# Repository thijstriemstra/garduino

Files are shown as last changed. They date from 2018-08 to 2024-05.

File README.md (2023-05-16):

Garduino
========

Greenhouse monitoring using ESP32.

## Features

- Controls 24V water waterpump and starts it once a day to water the plants for
  a period of time
- Device status is displayed on a small 0.91 inch OLED screen
- Includes a manual mode button to enable/disable the water valve manually
- Time is stored in a battery-powered DS3231 realtime clock

### Sensors

| Target | Sensor | Location | Amount |
| --- | --- | --- | --- |
| Light | TSL2591 | Inside | 1 |
| Soil moisture | Capacitive Soil Moisture Sensor v2.0 | Inside | 8 |
| Temperature/pressure/humidity | BME280 | Inside | 1 |
| Air temperature | DS18B20 | Outside | 1 |
| Water temperature | DS18B20 | Outside | 1 |

Readings from the sensors are sent to a MQTT server over WiFi (if available).

## Wiring

### AZ-Delivery Devkit V4

| Device | Pin Label | ESP32 Pin | Type |
| --- | --- | --- | --- |
| TCA9548A I2C Expander | SDA | `4` | I2C bus 0 (address: `0x70`) |
| TCA9548A I2C Expander | SCL | `22` | I2C bus 0 (address: `0x70`) |
| DS3231 Realtime Clock | SDA | `4` | I2C bus 0 (address: `0x68`) |
| DS3231 Realtime Clock | SCL | `22` | I2C bus 0 (address: `0x68`) |
| AT24C32 EEPROM on DS3231 | SDA | `4` |  I2C bus 0 (address: `0x57`) |
| AT24C32 EEPROM on DS3231 | SCL | `22` |  I2C bus 0 (address: `0x57`) |
| PCF8574 Digital Expander | SDA | `4` |  I2C bus 0 (address: `0x20`) |
| PCF8574 Digital Expander | SCL | `22` |  I2C bus 0 (address: `0x20`) |
| MCP3008 Analog Expander | CLK | `18` | SCK |
| MCP3008 Analog Expander | DOUT | `19` | MISO |
| MCP3008 Analog Expander | DIN | `23` | MOSI |
| MCP3008 Analog Expander | CS | `5` | SS |
| DS18B20 Temperature Sensors | GPIO | `13` | Digital Input |
| Buzzer | GPIO | `25` | Digital Output |
| Single Channel Relay | GPIO | `26` | Digital Output |
| Manual Run Button | GPIO | `39` | Digital Input |
| Power Button | GPIO | `36` | Digital Input |

### TCA9548A

| Device | Pin Label | TCA9548A Pin | Address |
| --- | --- | --- | --- |
| TSL2591 light sensor | SDA | `SD0` | `0x29` |
| TSL2591 light sensor | SCL | `SC0` | `0x29` |
| BME280 barometer | SDA | `SD1` | `0x76` |
| BME280 barometer | SCL | `SC1` | `0x76` |
| 0.91" OLED Display | SDA | `SD2` | `0x3C` |
| 0.91" OLED Display | SCL | `SC2` | `0x3C` |

### PCF8574

| Device | Type | PCF8574 Pin |
| --- | --- | --- |
| Watering Indication LED (White) | Digital Output | `0` |
| Manual Run LED (Yellow) | Digital Output | `2` |
| Network LED (Blue) | Digital Output | `1` |
| Power LED (Red) | Digital Output | `3` |

### MCP3008

| Device | Type | MCP3008 Pin |
| --- | --- | --- |
| Capacitive Soil 1 | Analog Input | `0` |
| Capacitive Soil 2 | Analog Input | `1` |
| Capacitive Soil 3 | Analog Input | `2` |
| Capacitive Soil 4 | Analog Input | `3` |
| Capacitive Soil 5 | Analog Input | `4` |
| Capacitive Soil 6 | Analog Input | `5` |
| Capacitive Soil 7 | Analog Input | `6` |
| Capacitive Soil 8 | Analog Input | `7` |

## 3D Printable Parts

| Part | Amount |
| --- | --- |
| [Buck converter bottom](cad/buck-converter-bottom.stl) | 1 |
| [Buck converter top](cad/buck-converter-top.stl) | 1 |
| [Buck converter icon](cad/buck-converter-icon.stl) | 1 |
| [Buck converter latch](cad/buck-converter-latch.stl) | 2 |

## Output

Example of cycle report on serial line:

```
00:00:00.063  ========================
00:00:00.064  =    garduino v4.0.0   =
00:00:00.064  ========================
00:00:00.065  Board:       AZ-Delivery ESP-32 Dev Kit C V4
00:00:00.075  Arduino:     2.0.7
00:00:00.075  ESP-IDF:     v4.4.4
00:00:00.080  Local time:  17:46:17
00:00:00.485  *******************************************
00:00:00.486  Wakeup reason: timer (60 sec)
00:00:00.487  *******************************************
00:00:00.488  WiFi - SSID: my_ssid
00:00:00.499  WiFi - Connecting...
00:00:00.708  WiFi - Connected.
00:00:00.709  WiFi - Hostname: garduino
00:00:00.709  Wifi - IP address: 192.168.2.2
00:00:00.710  ================================
00:00:00.721  MQTT - Timeout set to 30 seconds
00:00:00.721  MQTT - Broker: 192.168.2.1:1883
00:00:00.722  MQTT - Connecting...
00:00:00.775  MQTT - Connected.
00:00:00.776  ================================
00:00:00.777
00:00:00.777  ************************************
00:00:00.778        Watering: No
00:00:00.788          Period: 60 sec
00:00:00.789  Daily schedule: 19:00:00
00:00:00.789    Current time: 17:46:17
00:00:00.791        Last run: 2023-03-21 19:08:11
00:00:00.802  ************************************
00:00:00.802
00:00:00.803  MQTT - Publishing sensor data...
00:00:00.813
00:00:00.814  Inside
00:00:00.814  ------
00:00:00.814
00:00:00.815  Light:            350.67 lx
00:00:00.821  Humidity:         44.5%
00:00:00.822  Temperature:      25.14 °C
00:00:00.822  Pressure:         1002.44 hPa
00:00:00.840  Soil-1 wet:       0%
00:00:00.841  Soil-2 wet:       0%
00:00:00.851  Soil-3 wet:       0%
00:00:00.852  Soil-4 wet:       0%
00:00:00.852  Soil-5 wet:       0%
00:00:00.852  Soil-6 wet:       0%
00:00:00.853  Soil-7 wet:       98%
00:00:00.863  Soil-8 wet:       0%
00:00:00.854  System:           23.75 °C
00:00:00.854
00:00:00.854  Outside
00:00:00.855  -------
00:00:00.865
00:00:00.962  Temperature:      17.75 °C
00:00:00.967
00:00:00.967  Water
00:00:00.967  -----
00:00:00.967
00:00:00.968  Temperature:      18.25 °C
00:00:00.968
00:00:00.968  WIFI
00:00:00.969  ----
00:00:00.979
00:00:00.981  RSSI:             -63 dBm
00:00:00.981
00:00:00.981  **********************************************
00:00:00.982
00:00:16.558  MQTT - Published 16 messages.
00:00:16.559  MQTT - Disconnecting...
00:00:16.863
00:00:16.864  ******************************
00:00:16.865  **  Going to sleep... Bye.  **
00:00:16.866  ******************************
```

## Local NTP Server

Setup a local NTP server instead of fetching this information online every
time.

```console
sudo apt-get install ntp
```

Verify installation:

```console
sntp --version
```

Switch the server pool to the ones closest to your location. Go to
https://support.ntp.org/bin/view/Servers/NTPPoolServers and find the
nearest pool, e.g. Europe. Update `/etc/ntp.conf` accordingly:

```
	   server 0.europe.pool.ntp.org
	   server 1.europe.pool.ntp.org
	   server 2.europe.pool.ntp.org
	   server 3.europe.pool.ntp.org
```

Restart the server:

```console
sudo service ntp restart
```

Check the status:

```console
 sudo service ntp status
 ```

You can now use this machine for NTP time synchronization on the ESP32.

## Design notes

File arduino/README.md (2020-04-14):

Arduino code for garden monitoring using ESP32.

This project was created using a Lolin32 Lite v1.0.0.

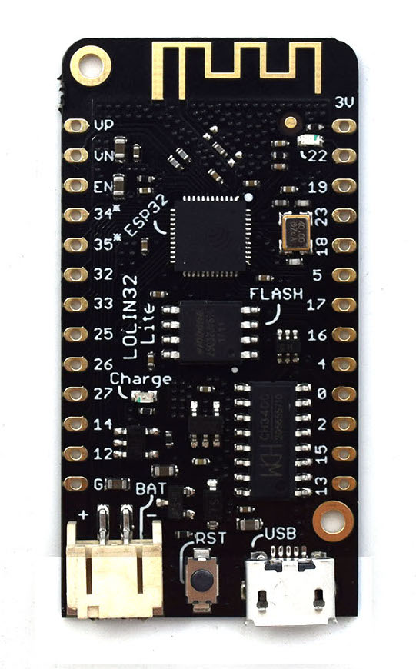
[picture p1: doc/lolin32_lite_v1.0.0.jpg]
Lolin32 Lite


## Installation

Checkout code:

```console
git clone https://github.com/thijstriemstra/py-garden.git
cd py-garden/arduino
```

## Development

Open `pygarden` project in VSCode with PlatformIO IDE extension.

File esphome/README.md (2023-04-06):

# ESPHome

Checkout the code:

```console
git clone https://github.com/thijstriemstra/garduino.git
cd garduino
```

Create a [virtual environment](https://virtualenvwrapper.readthedocs.io/en/latest/index.html)
called `garduino`:

```console
mkvirtualenv garduino
```

Install the dependencies:

```console
pip install -e .
```

Verify installation:

```console
esphome version
```

Create `secrets.yaml`:

```console
touch secrets.yaml
```

And make sure to add all options marked with `!secret` in `garduino.yaml`.

### Upload

Plug in the device via USB and type the following command:

```console
esphome run garduino.yaml
```

You should see ESPHome validating the configuration and telling you about
potential problems. Then ESPHome will proceed to compile and upload the
custom firmware.

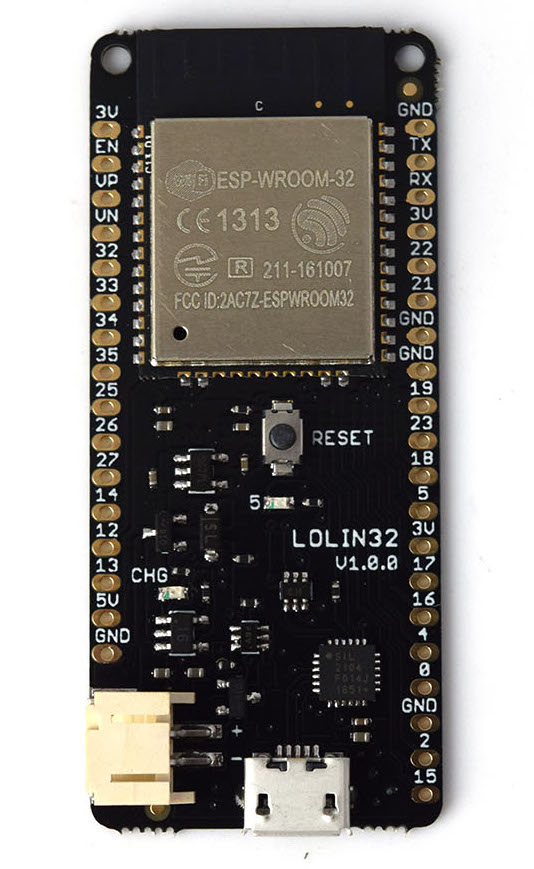
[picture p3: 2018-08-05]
micropython/doc/lolin32_v1.0.0.jpg

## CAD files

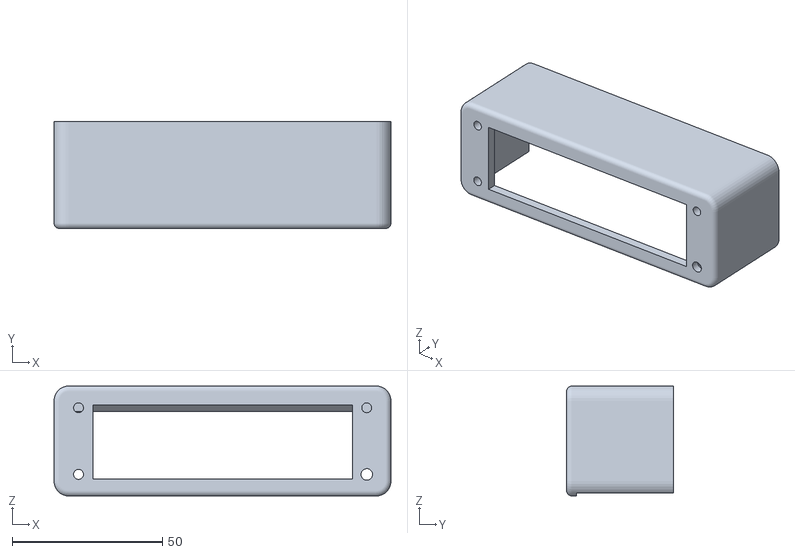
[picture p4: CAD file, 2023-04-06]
cad/Bottom Cover.stl
112.0 x 35.5 x 36.6

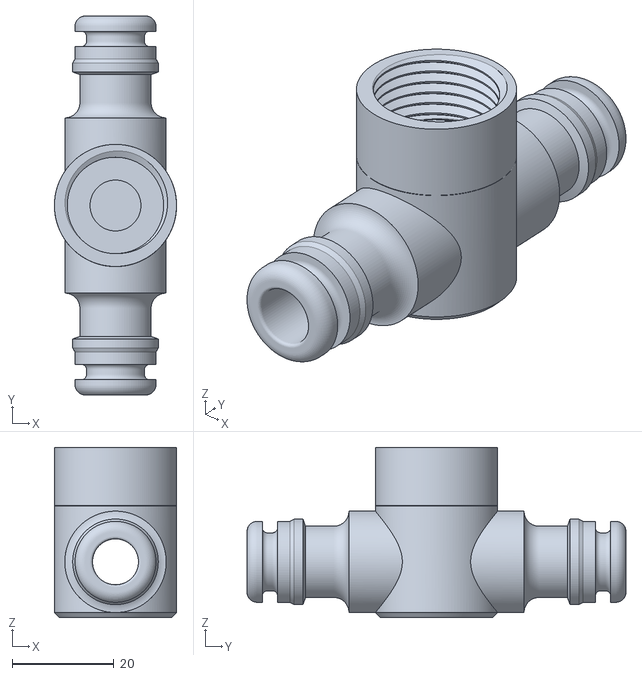
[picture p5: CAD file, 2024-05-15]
cad/irrigation/middle_section_2gardena_v1_0.5NTP.stl
24.0 x 74.4 x 33.4

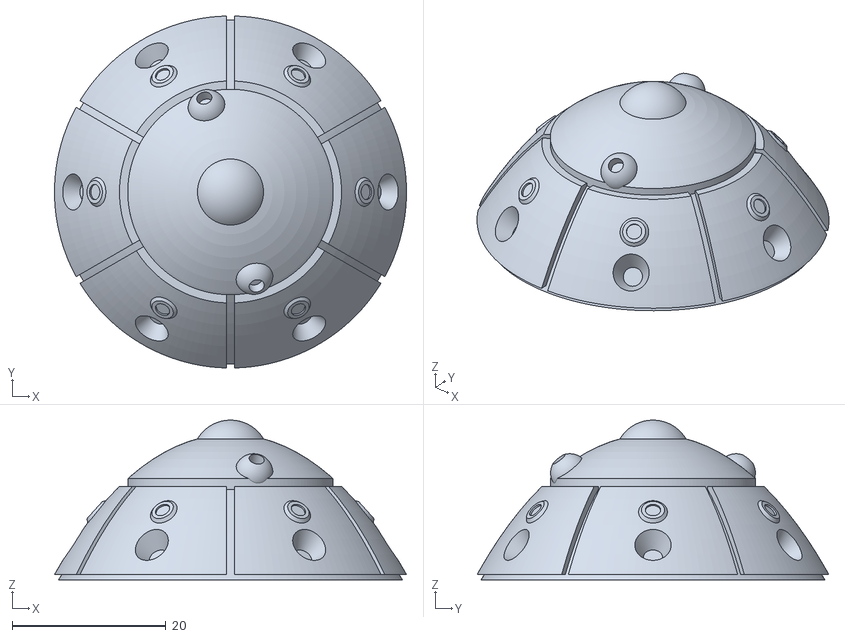
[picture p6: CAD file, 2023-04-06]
cad/sensors/top.stl
45.8 x 45.8 x 20.8

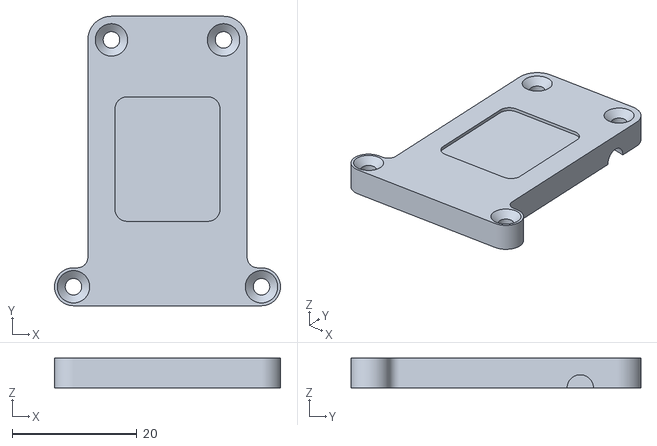
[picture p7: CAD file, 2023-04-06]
cad/soil/soil-sensor-lid.stl
36.3 x 46.5 x 4.80

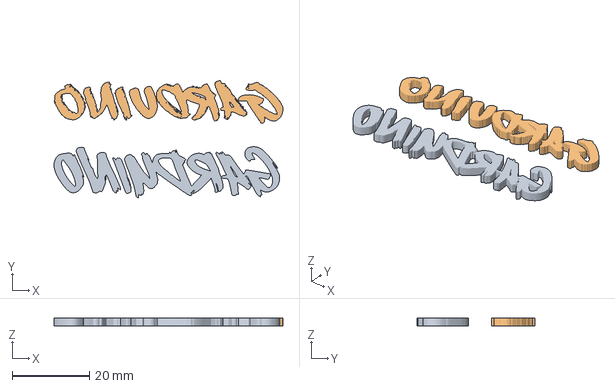
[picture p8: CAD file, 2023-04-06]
cad/Garduino-logo .3mf
59.3 x 30.5 x 2.00 mm
Garduino
Garduino

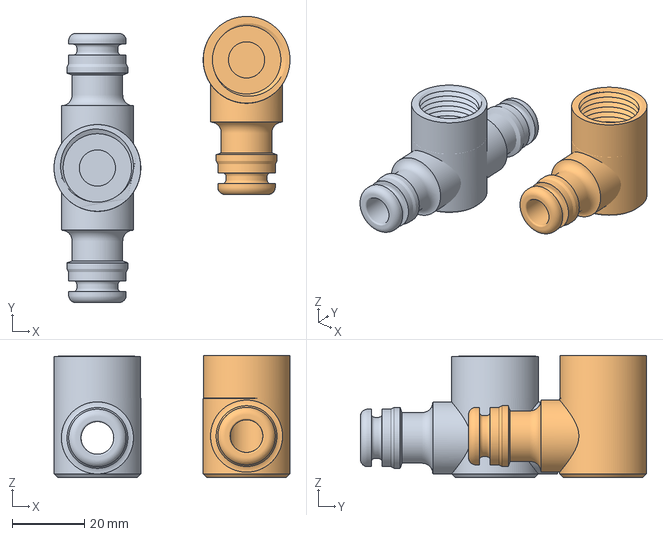
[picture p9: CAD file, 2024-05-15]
cad/irrigation/middle_section_0.5NTP.3mf
65.2 x 79.1 x 33.7 mm
middle_section_2gardena_v1_0.5NTP.stl
middle_section_1gardena_v1_0.5NTP.stl

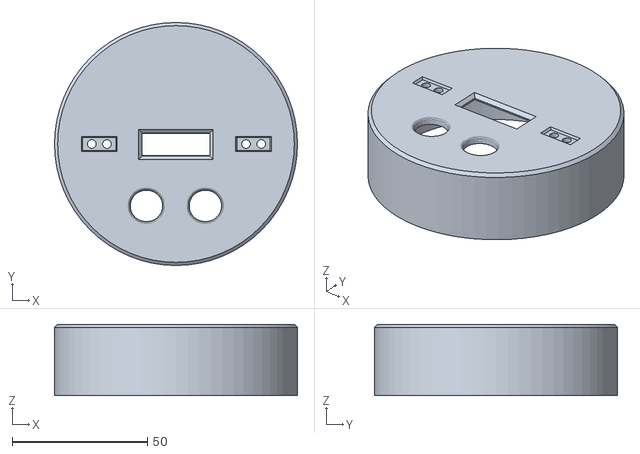
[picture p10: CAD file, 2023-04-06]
cad/sensors/ctrl-panel-cap.stl
90.0 x 90.0 x 26.4

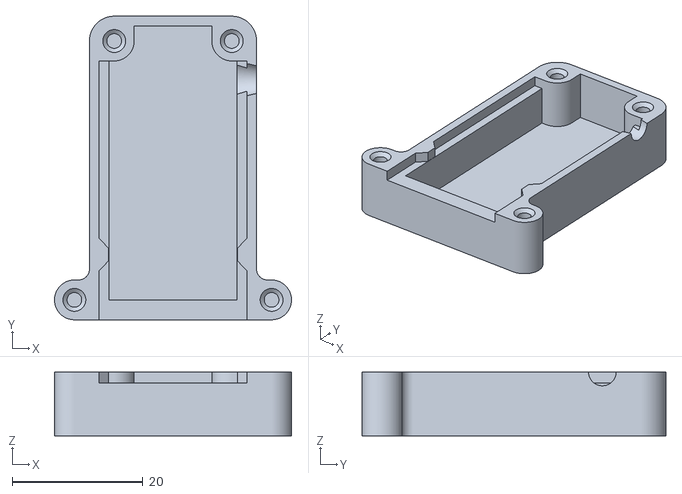
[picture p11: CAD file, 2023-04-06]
cad/soil/soil-sensor-box.stl
36.3 x 46.5 x 9.80

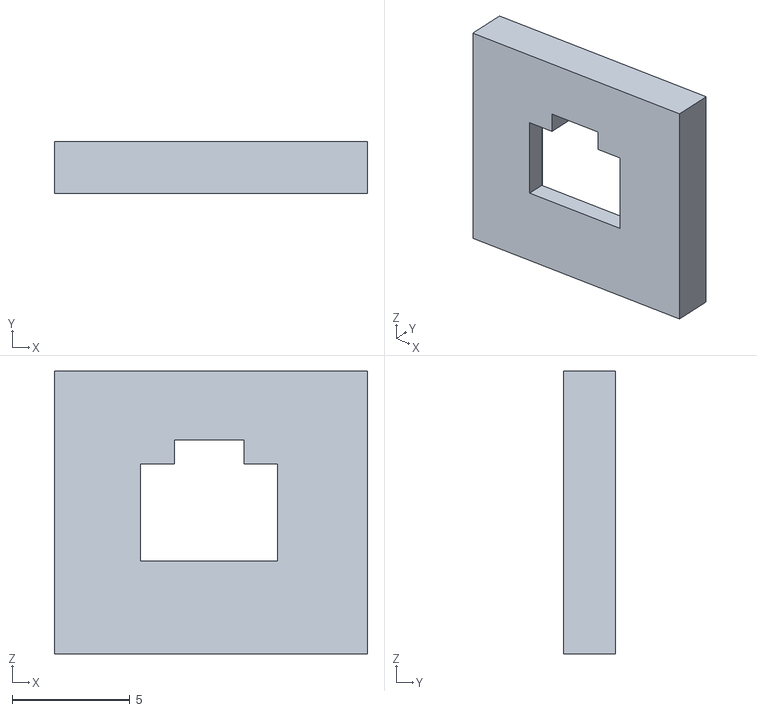
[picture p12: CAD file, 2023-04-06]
cad/conn-2-pin-cover.stl
13.3 x 2.20 x 12.0

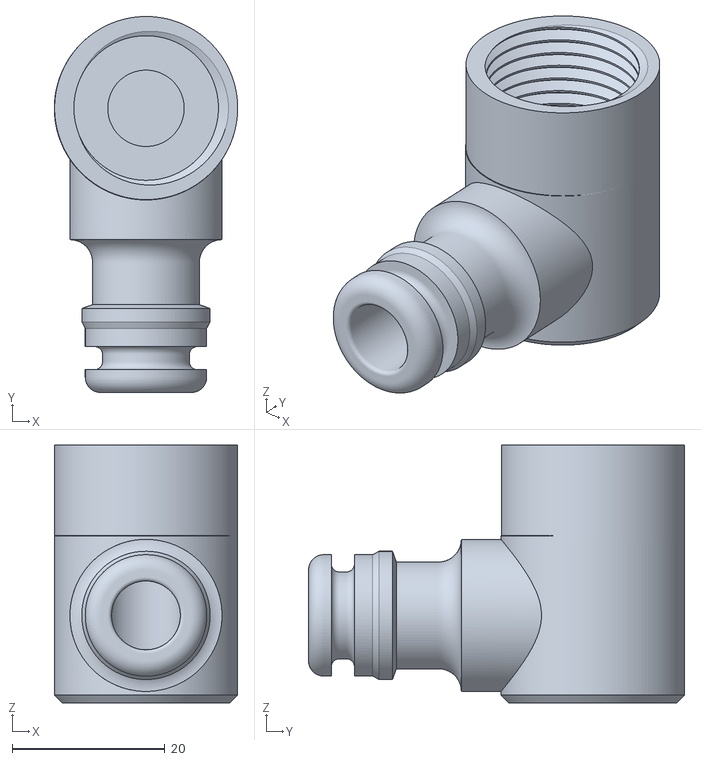
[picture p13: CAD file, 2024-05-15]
cad/irrigation/middle_section_1gardena_v1_0.5NTP.stl
24.0 x 49.2 x 33.7

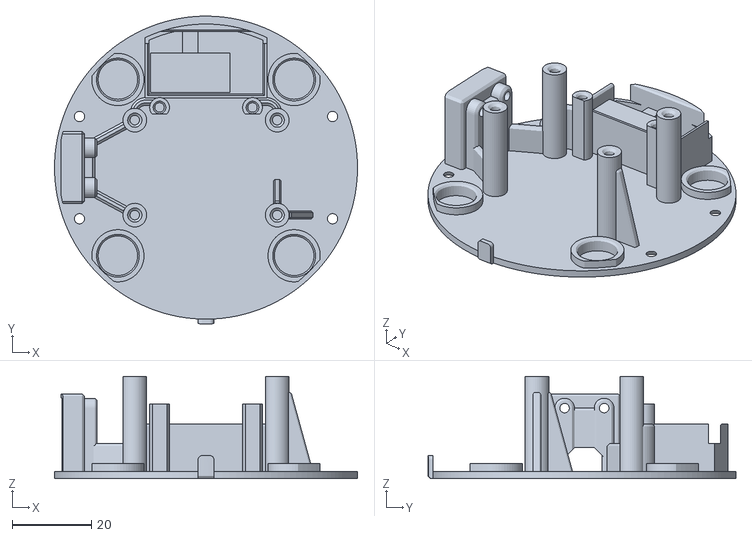
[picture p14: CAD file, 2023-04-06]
cad/sensors/ctrl-panel-bottom.stl
76.6 x 77.8 x 25.8

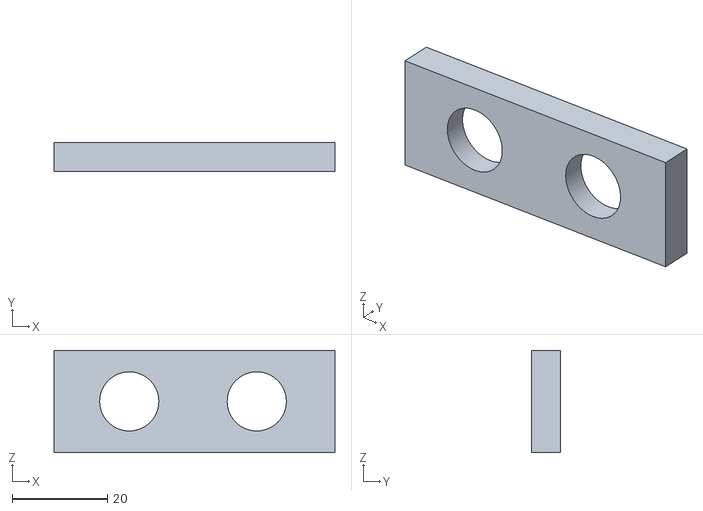
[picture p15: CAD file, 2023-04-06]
cad/case-connectors.stl
58.9 x 6.17 x 21.4

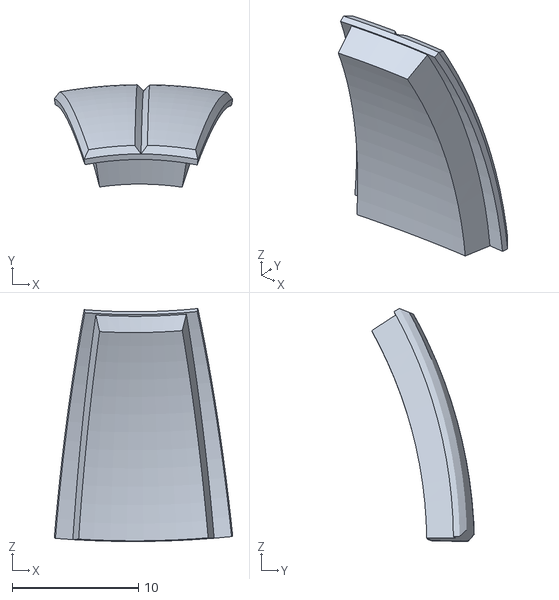
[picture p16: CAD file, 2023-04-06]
cad/sensors/door1.stl
14.2 x 8.13 x 18.5

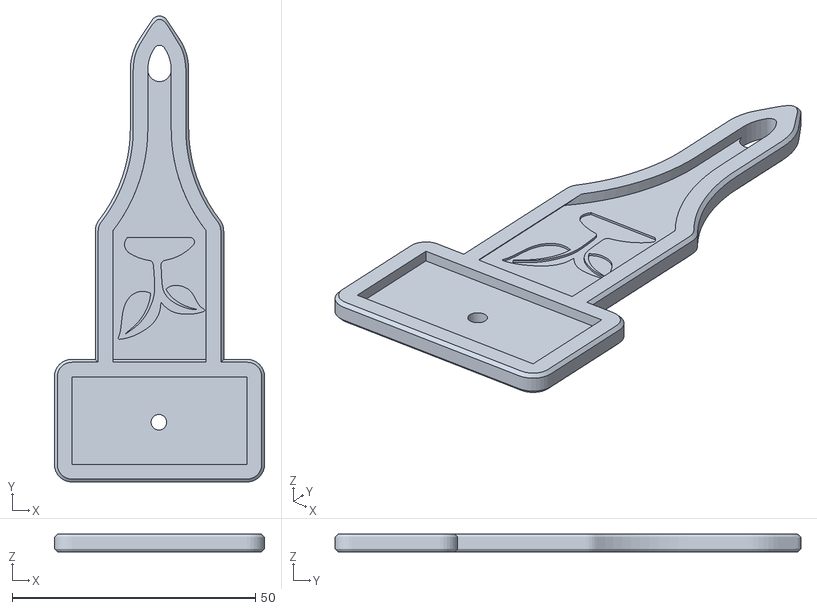
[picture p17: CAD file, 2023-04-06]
cad/plant-label.stl
43.2 x 95.8 x 3.60

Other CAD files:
cad/sensors/ring.stl
cad/plant-label-card.stl
cad/sensors/icon-moon.stl
cad/handle-right.stl
cad/Bottom Connectors.stl
cad/Bottom Shell PCB only.stl
cad/Top Shell.stl
cad/bme280-holder.stl
cad/bme280-top.stl
cad/buck-converter-bottom.stl
cad/buck-converter-icon.stl
cad/buck-converter-latch.stl
cad/buck-converter-top.stl
cad/buck-converter.blend
cad/case-bottom.stl
cad/case-top.stl
cad/conn-6-pin-cover.stl
cad/mcp3008.blend
cad/plant-label.blend
cad/sensors/case-bottom.stl
cad/sensors/case-top.stl
cad/sensors/ctrl-panel-button-cap.stl
cad/sensors/ctrl-panel-description.stl
cad/sensors/ctrl-panel-front.stl
cad/sensors/ctrl-panel-top.stl
cad/sensors/door2.stl
cad/sensors/icon-play.stl
cad/sensors/icon-power.stl
cad/sensors/thrusters.stl
cad/soil/soil-sensor.blend
cad/tsl2591-light-sensor.stl

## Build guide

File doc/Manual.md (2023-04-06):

# Garduino Manual

De Garduino geeft dagelijks om 19:00 uur de planten enige tijd water.

## Handmatige bediening

Je kan met de MANUAL knop de planten handmatig water geven.

In manual mode word er ook iedere 4 seconden op het display afwisselend
verschillende data weergegeven, zoals de huidige temperatuur en tijd.

### Stappen voor handmatig watergeven

1. Druk op de MANUAL knop tot de temperatuur op het display te zien is.
   Als het oranje licht op de voorzijde brandt, ga naar stap 2.

2. Druk nogmaals op de MANUAL knop om de waterpomp te starten.
   Het witte licht op de voorzijde brandt nu en op het display
   is 'Open' te zien.

3. Druk nogmaals op de MANUAL knop om de waterpomp te stoppen.
   Het witte licht op voorzijde zal uitgaan en op het display
   is weer 'Closed' te zien. Na 5 seconden zal de temperatuur
   en tijd weer afwisselend worden weergegeven.

4. Druk op de SLEEP knop om de Garduino weer het automatische
   programma te laten volgen. Op de voorzijde moeten nu alle lichten
   en het display uit zijn.

Vergeet niet stap 4 anders start de Garduino het automatische programma
niet op (en zal er dagelijks dus geen water worden gegeven).

---

v4.0.0

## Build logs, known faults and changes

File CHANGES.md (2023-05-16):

Garduino changelog
==================

4.1.0 (unreleased)
------------------

- Replace BH1750 with TSL2591 light sensor

4.0.0 (2023-04-08)
------------------

- Add buzzer
- Remove waterflow meter
- Fix soil sensors
- Add PC8574
- Unpin and use latest RTClib
- Add V4 CAD models

3.4.0 (2022-03-13)
------------------

- Pin RTClib @ 1.13.0

3.2.0 (2021-06-30)
------------------

- Display time and temperature on display
- Bug fixes

3.0.0 (2021-05-19)
------------------

Add support for:

- TCA9548A I2C expander
- MCP3008 analog expander

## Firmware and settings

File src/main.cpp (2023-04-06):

/*
* Copyright (c) 2020-2023 Collab
* All rights reserved
*/

#include "Garduino.h"

// *************************************************************************
//  Uncomment line below to fully disable logging, and reduce project size
// ************************************************************************
//#define DISABLE_LOGGING

#define SERIAL_BAUD_RATE 115200

Garduino *app = new Garduino();

void setup() {
  // start serial connection
  Serial.begin(SERIAL_BAUD_RATE);

  app->begin();
}

void loop() {
  app->loop();
}

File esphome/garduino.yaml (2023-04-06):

esphome:
  name: garduino

  project:
    name: "thijstriemstra.garduino"
    version: "4.0.0"

  platformio_options:
    upload_speed: 115200

#  on_boot:
#    then:
#      # read the RTC time once when the system boots
#      ds1307.read_time:

esp32:
  board: az-delivery-devkit-v4
  framework:
    type: arduino

# Enable logging
logger:

# Enable Home Assistant API
#api:
#  password: ""

ota:
  password: ""

wifi:
  ssid: !secret wifi_ssid
  password: !secret wifi_password
  # The amount of time to wait before rebooting when no WiFi connection exists.
  reboot_timeout: 15min

  # Enable fallback hotspot (captive portal) in case wifi connection fails
  ap:
    ssid: !secret hotspot_ssid
    password: !secret hotspot_password
    # The time after which to enable the configured fallback hotspot
    ap_timeout: 1min

captive_portal:

# ---------------------------
# Fonts
# ---------------------------
font:
  - file: "fonts/Arimo-Regular-Latin.ttf"
    id: arimo_regular_20
    size: 20
  - file: "fonts/Arimo-Regular-Latin.ttf"
    id: arimo_regular_30
    size: 30

# -----------------------------------
# Dallas temperature sensor (DS18B20)
# -----------------------------------

#dallas:
#  - pin: GPIO13

# -----------------------------------
# I2C
# -----------------------------------
#  - Bus 0: DS3231 RTC (0x68)
#  - Bus 0: AT24C32 EEPROM on DS3231 (0x57)
#  - Bus 1: TCA9548A I2C expander (0x70)
i2c:
  - id: bus_0
    frequency: 200kHz
    sda: GPIO16
    scl: GPIO17
    scan: true
  - id: bus_1
    frequency: 200kHz
    sda: GPIO4
    scl: GPIO22
    scan: true

# I2C expander:
#  - Channel 0: BH1750 light sensor (0x23)
#  - Channel 1: BME280 barometer (0x76)
#  - Channel 2: SSD1306 OLED (0x3C)
tca9548a:
  - id: multiplex0
    address: 0x70
    i2c_id: bus_1
    channels:
      - bus_id: multiplex0channel0
        channel: 0
      - bus_id: multiplex0channel1
        channel: 1
      - bus_id: multiplex0channel2
        channel: 2

# -----------------------------------
# SPI
# -----------------------------------
#  - MCP3008 analog expander
#spi:
#  clk_pin: GPIO18
#  mosi_pin: GPIO23
#  miso_pin: GPIO19

# Analog expander:
#  - Capacitive Soil Sensor x 5
#mcp3008:
#  id: soil_mcp
#  cs_pin: GPIO5

# ---------------------------
# Sensors
# ---------------------------

#sensor:
#  - platform: bh1750
#    name: "BH1750 Illuminance"
#    i2c_id: multiplex0channel0
#    address: 0x23
#    update_interval: 60s
#
#  - platform: bme280
#    temperature:
#      name: "BME280 Temperature"
#      oversampling: 16x
#    pressure:
#      name: "BME280 Pressure"
#    humidity:
#      name: "BME280 Humidity"
#    address: 0x76
#    update_interval: 60s
#    i2c_id: multiplex0channel1

#  - platform: dallas
#    address: 0xA40000031F055028
#    name: "Temperature #1"

#  - platform: mcp3008             # Attached to pin 0 of the MCP3008.
#    reference_voltage: 3.19
#    update_interval: 1s
#    mcp3008_id: soil_mcp
#    id: freezer_temp_source
#    number: 0                     # MCP3008 pin number
#  - platform: resistance
#    id: freezer_resistance_sensor
#    sensor: freezer_temp_source
#    configuration: DOWNSTREAM
#    resistor: 10kOhm
#  - platform: ntc
#    id: freezer_temp
#    sensor: freezer_resistance_sensor
#    calibration:
#      b_constant: 3950
#      reference_temperature: 25°C
#      reference_resistance: 10kOhm
#    name: Freezer Temperature

# ---------------------------
# Display
# ---------------------------

display:
  - platform: ssd1306_i2c
    model: "SSD1306 128x32"
    i2c_id: multiplex0channel2
    external_vcc: true
    address: 0x3C
    contrast: 100%
    rotation: 0°
    flip_x : true
    flip_y: true
    invert: false
    update_interval: 1s
    lambda: |-
      it.line(0, 0, 10, 20);

# ---------------------------
# Relay
# ---------------------------

#switch:
#  - platform: gpio
#    name: "Relay"
#    pin: GPIO2

# ---------------------------
# Buttons
# ---------------------------

#binary_sensor:
#  # Manual run button
#  - platform: gpio
#    pin: GPIO36
#    name: "Manual"
#    filters:
#      - delayed_on: 10ms
#
#  # Power button
#  - platform: gpio
#    pin: GPIO39
#    name: "Power"
#    filters:
#      - delayed_on: 10ms

# ---------------------------
# LED
# ---------------------------

#status_led:
#  pin:
#    number: GPIO33
#    inverted: false

output:
  # Watering indication LED
  - platform: gpio
    pin: GPIO25
    id: watering_led

  # Manual run LED
  - platform: gpio
    pin: GPIO26
    id: manual_led

  # Network LED
  - platform: gpio
    pin: GPIO33
    id: network_led

  # Power LED
  - platform: gpio
    pin: GPIO27
    id: power_led
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

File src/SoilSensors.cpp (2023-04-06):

/*  Copyright (c) 2020-2023, Collab
 *  All rights reserved
*/
/*
  SoilSensors.cpp - Read multiple Capacitive Soil Moisture Sensors.
*/
#include "SoilSensors.h"

SoilSensors::SoilSensors(SoilSensorsConfig cfg, MultiPlexer_MCP3008 *adc) {
  _soil1 = new Capacitive_SoilSensor_MCP3008(adc, cfg.sensor1_channel, cfg.sensor1_wet, cfg.sensor1_dry);
  _soil2 = new Capacitive_SoilSensor_MCP3008(adc, cfg.sensor2_channel, cfg.sensor2_wet, cfg.sensor2_dry);
  _soil3 = new Capacitive_SoilSensor_MCP3008(adc, cfg.sensor3_channel, cfg.sensor3_wet, cfg.sensor3_dry);
  _soil4 = new Capacitive_SoilSensor_MCP3008(adc, cfg.sensor4_channel, cfg.sensor4_wet, cfg.sensor4_dry);
  _soil5 = new Capacitive_SoilSensor_MCP3008(adc, cfg.sensor5_channel, cfg.sensor5_wet, cfg.sensor5_dry);
  _soil6 = new Capacitive_SoilSensor_MCP3008(adc, cfg.sensor6_channel, cfg.sensor6_wet, cfg.sensor6_dry);
  _soil7 = new Capacitive_SoilSensor_MCP3008(adc, cfg.sensor7_channel, cfg.sensor7_wet, cfg.sensor7_dry);
  _soil8 = new Capacitive_SoilSensor_MCP3008(adc, cfg.sensor8_channel, cfg.sensor8_wet, cfg.sensor8_dry);
}

void SoilSensors::begin() {
}

SoilMoistureResult SoilSensors::readAll() {
  SoilMoistureResult result;
  result.sensor1 = _soil1->measure();
  result.sensor2 = _soil2->measure();
  result.sensor3 = _soil3->measure();
  result.sensor4 = _soil4->measure();
  result.sensor5 = _soil5->measure();
  result.sensor6 = _soil6->measure();
  result.sensor7 = _soil7->measure();
  result.sensor8 = _soil8->measure();

  return result;
}

SoilMoistureResult SoilSensors::readAllPercentage() {
  SoilMoistureResult result;
  result.sensor1 = _soil1->measurePercentage();
  result.sensor2 = _soil2->measurePercentage();
  result.sensor3 = _soil3->measurePercentage();
  result.sensor4 = _soil4->measurePercentage();
  result.sensor5 = _soil5->measurePercentage();
  result.sensor6 = _soil6->measurePercentage();
  result.sensor7 = _soil7->measurePercentage();
  result.sensor8 = _soil8->measurePercentage();

  return result;
}

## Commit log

2018-07-06 Refactor (#2)
    * move external libs
    * deinit rtc i2c
    * add connected callback
    * use convert_read
    * add flake8 config
    * exit on script error
    * add mqtt module
    * setup sensors using config
    * add config example
    * add LightSensorError
    * add auto_start
2018-07-10 disable sensors before deepsleep
2018-07-30 turn sensor on before usage
2018-08-05 TM-1637 display support (#5)
    * add tm1637 display support
    * add 3-way switch class
    * add display and switch modules
    * add fritzing sketch
    * add tox qa on travis build
    * bump version: 0.1.0
    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
    [sketch-lolin32.fzz]
2020-04-02 move to micropython dir
    [sketch-lolin32.fzz]
2020-04-02 move doc
    [sketch-lolin32.fzz]
2020-04-02 add arduino project
2020-04-10 start of arduino version
2020-04-10 add more sensors
2020-04-10 add light sensor
2020-04-18 add relay
2020-04-19 fix temperature calls
2020-04-19 add distance sensor
2020-04-19 enable all sensors
2020-04-24 remove distance sensor
2020-04-24 change to pin 14
2020-04-24 add BMP280 sensor
2020-04-25 add sensors
2020-04-27 add manual run led
2020-04-27 add LED
2020-04-27 blink led until mqtt connection
2020-04-28 add Sensors class
2020-04-28 add power management
2020-05-02 manual led is always enabled in manual mode
2020-05-02 enable led earlier
2020-05-02 log system temperature
2020-05-02 remove device boot count
2020-05-02 add WateringIndication led and mqtt timeout setting
2020-05-02 dont automatically open valve when pressing manual mode button
2020-05-03 publish valve open/closed
2020-05-03 move indication led
2020-05-21 add water flow meter
2020-05-22 store water flow meter volume
2020-05-22 add FlowMeter lib
2020-06-28 Use multiplexer for rain and soil sensors (#6)
    * work on multiplexer
    * dont hardcode size
    * bump version: 2.3.0
    * use YL83_RainSensor_Mux
2020-06-28 enable travis build (#7)
    * enable travis build
    * update path
    * add project conf param
    * cache and update pip
    * update lib linkage
    * add missing includes
    * replace symlinks with lib extra dir
    * move to root dir
    * use src dir
    * use lib option
    * use env
    * use file extension
    * dont use lib
    * try this
    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
    [IOT.cpp, PyGarden.cpp]
2020-07-13 Use soil sensors (#8)
    * update
    * calibrated soil sensors
2020-10-18 add cad files
    [Main-panel-bottom.stl, Main-panel-top.stl, Main-panel.blend]
2021-05-19 v3.0 (#9)
    * add changelog
    * add controls
    * add multiplexers
    * update wiring
    * switch to rtclib
    * it's a lolin32 lite
    * sensors update
    * fix datetime save/load
    * add utils
    * use f string
    * use BH1750_WE
    * use esp32 Tasks
    [Garduino.cpp, IOT.cpp]
2021-06-16 fix race condition with mqtt
    [Garduino.cpp, IOT.cpp]
2021-06-16 show temperature in manual mode
2021-06-30 add countdown for valve open/close
2021-07-01 add esp32_exception_decoder monitor filter
2021-07-06 Delete lolin32_v1.0.0.jpg
    not using this board
2021-07-31 add Wire bus doc
2022-04-15 cad: add buck converter case
    [buck-converter-bottom.stl, buck-converter-latch.stl, buck-converter-top.stl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]
2022-04-18 cad update
    [buck-converter.blend]
2022-04-19 cad: update icon to buck converter
    [buck-converter-bottom.stl, buck-converter-icon.stl, buck-converter-top.stl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]
2022-04-20 main panel cad update
    [Main-panel-bottom.stl, Main-panel-button-mount.stl, Main-panel-button.stl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]
2022-04-24 cad: top update
    [Main-panel-top.stl, Main-panel.blend]
2022-04-25 pin to 3.x for now
2023-04-06 v4 (#11)
    * ci: update step versions
    * add more sensors
    * update pin nr
    * remove old cad files
    * doc: add esp32 pinout
    * cad: add sensors model
    * set hostname
    * happy new year
    * use latest espressif32, add pcf8574 and switch to different board type
    * use 1 i2c bus, add PCF8574
    * bump version: 4.0.0
    * moved LEDs to PCF8574
    * add buzzer and more soil sensors
    * remove water flow meter
    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
    [Bottom Connectors.stl, Bottom Cover.stl, Bottom Shell PCB only.stl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]
2023-05-16 replace BH1750 with TSL2591 light sensor (#12)
